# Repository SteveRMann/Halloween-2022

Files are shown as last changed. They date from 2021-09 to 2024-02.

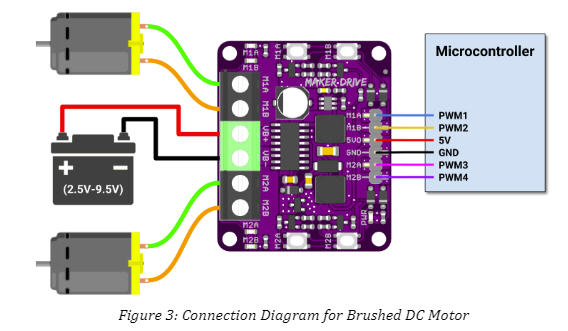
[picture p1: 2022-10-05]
tail-tentacle hardware/Maker Drive- H-Bridge Connections.jpg

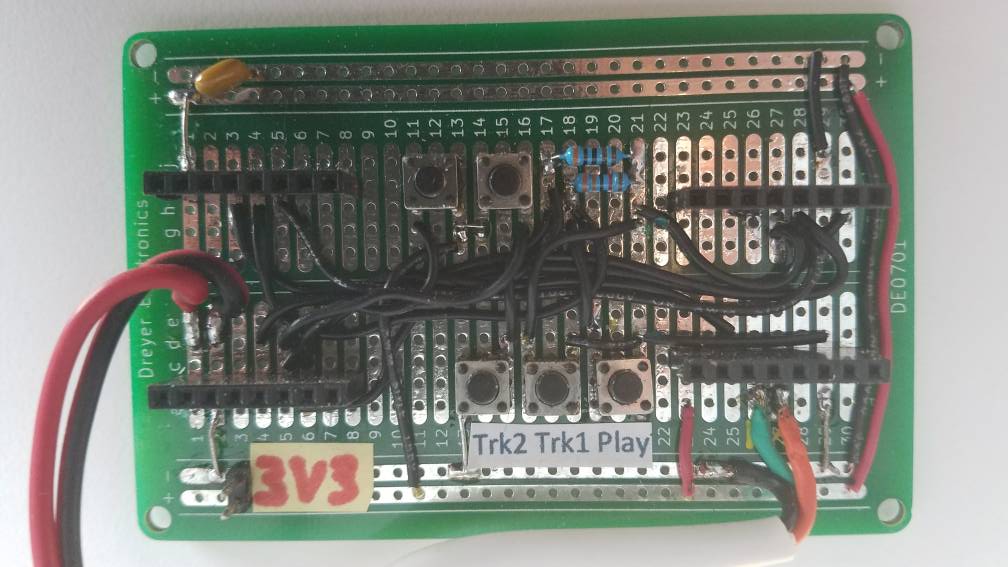
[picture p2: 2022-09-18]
Sounds/DFPlayer/Schematic/20220916_123933.jpg

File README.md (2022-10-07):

# MonsterBox
This project is further development of the 2021 monster in a box for Halloween.
The biggest change is the addition of a bubble generator.

## Crate Ideas
Contains images and ideas for the crate construction

## Fan
Contains the schematic files for the fan and LED MOSFET controller.

## Notes
Just contains random notes used while making the box

## Sounds
Contains the sound files and editing information. It also contains the DFPlayer notes.

## src
### dfPlayer
This is the code that controls the sounds from the box

### HBridgeTest
Code to test the H-Bridge. This year we changed to a library to control the tail H-bridge

### Lid
Contains the Arduino source code for the lid mechanism.

### servoSweep
Code to sweep the servo 0-180 degrees.

### servoManualSweep
Code used to calibrate the PWM endpoints for servo.h

### tail
Code to make the sea monster's tail sweep back and forth.

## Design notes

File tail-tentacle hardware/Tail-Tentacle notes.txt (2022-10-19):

The original breadboard had a PINHD-1X8 for the input side, but the production version uses six pins.

Prototype pinout:
1 - Ground
2 - +5V
3 - Ground
4 - +5V
5 - 5V isolation if the ESP is to be powered from the USB
6 - +5V to the ESP
7 - External trigger button
8 - Ground

The production version:
2 - Connects to the limit switch on D5

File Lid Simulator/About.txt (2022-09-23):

This is a motor controller for the lid simulator

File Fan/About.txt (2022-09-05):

The fan in the crate blows the fog out of the lid.

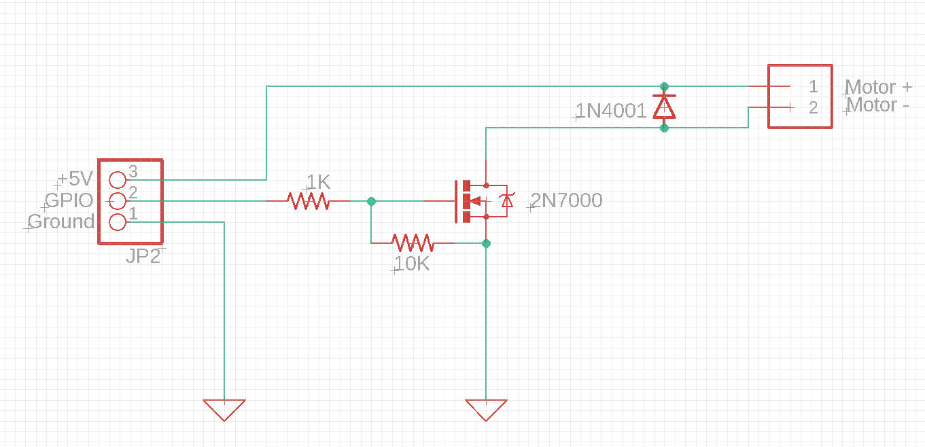
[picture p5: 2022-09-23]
Lid Simulator/Lid Simulator Schematic.jpg

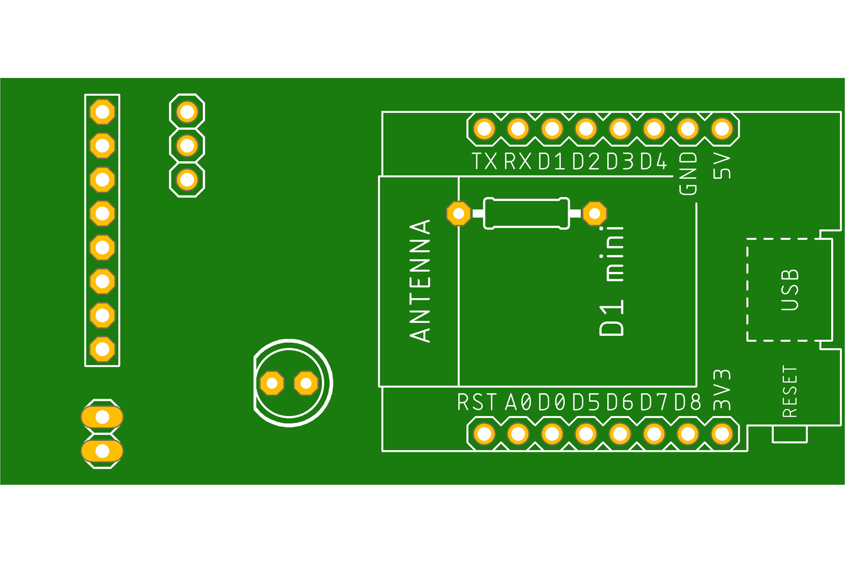
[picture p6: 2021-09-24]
tail-tentacle hardware/tail.png

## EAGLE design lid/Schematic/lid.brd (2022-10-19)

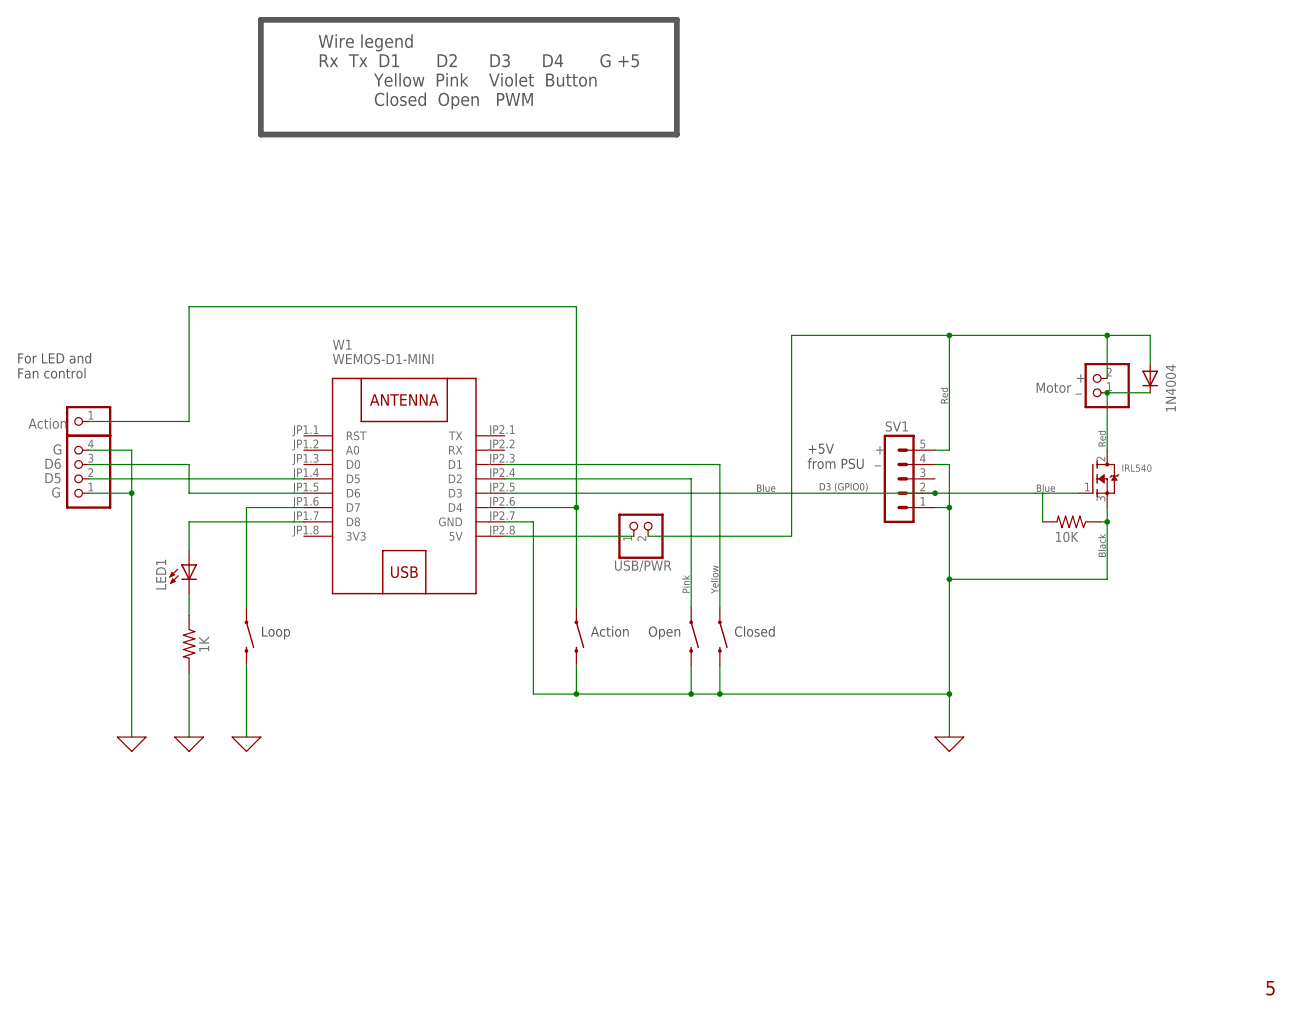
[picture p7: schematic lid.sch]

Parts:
ACTION, ACTION1: MOMENTARY-SWITCH-SPST-PTH-6.0MM; TACTILE_SWITCH_PTH_6.0MM
D1: 1N4004; DO41-10
JP1: PINHD-1X1; 1X01
JP3: PINHD-1X2; 1X02
JP4: PINHD-1X4; 1X04
LED1: LED5MM
Q1: IRL540; TO220V
R1: 1K; 0207/10
R4: 10K; 0207/10
S1, S2: MOMENTARY-SWITCH-SPST-PTH-6.0MM; TACTILE_SWITCH_PTH_6.0MM
SV1: MA05-1
USB/PWR: PINHD-1X2; 1X02
W1: WEMOS-D1-MINI

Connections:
0: ACTION.3 (2), ACTION1.3 (2), JP4.1, JP4.4, Q1.3 (S), R1.2, R4.1, S1.3 (2), S2.3 (2), SV1.1, SV1.4, W1.JP2.7 (GND)
3V3: W1.JP1.8 (3V3)
unnamed: Q1.1 (G), R4.2, SV1.2, W1.JP2.5 (D3)
unnamed: D1.C, JP3.1, Q1.2 (D)
unnamed: D1.A, JP3.2, SV1.5, USB/PWR.2
unnamed: S1.1, W1.JP2.4 (D2)
unnamed: S2.1, W1.JP2.3 (D1)
unnamed: LED1.A, W1.JP1.7 (D8)
unnamed: LED1.K (C), R1.1
unnamed: USB/PWR.1, W1.JP2.8 (5V)
unnamed: ACTION.1, JP1.1, W1.JP2.6 (D4)
unnamed: JP4.2, W1.JP1.4 (D5)
unnamed: JP4.3, W1.JP1.5 (D6)
unnamed: ACTION1.1, W1.JP1.6 (D7)

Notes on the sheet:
Motor
+5V from PSU
D3 (GPIO0)
Open
Closed
Yellow
Pink
Blue
Black
Red
Action
Wire legend Rx Tx D1 D2 D3 D4 G +5 Yellow Pink Violet Button Closed Open PWM
For LED and Fan control
Loop

Board: 2 copper layers, 15 parts (0 on the bottom side), 13 nets, no tracks yet.

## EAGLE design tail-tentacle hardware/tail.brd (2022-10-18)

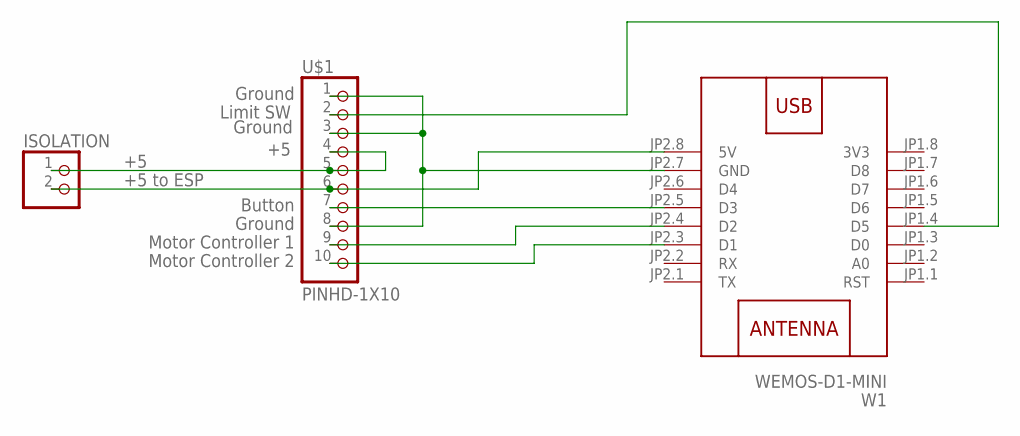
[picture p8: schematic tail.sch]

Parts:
ISOLATION: PINHD-1X2; 1X02
U$1: PINHD-1X10; 1X10-BIG
W1: WEMOS-D1-MINI

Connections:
3V3: W1.JP1.8 (3V3)
unnamed: U$1.7, W1.JP2.5 (D3)
unnamed: U$1.9, W1.JP2.4 (D2)
unnamed: U$1.10, W1.JP2.3 (D1)
unnamed: ISOLATION.1, U$1.4, U$1.5
unnamed: ISOLATION.2, U$1.6, W1.JP2.8 (5V)
unnamed: U$1.2, W1.JP1.4 (D5)
unnamed: U$1.1, U$1.3, U$1.8, W1.JP2.7 (GND)

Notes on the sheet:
Limit SW
Ground
Button
Motor Controller 1
Motor Controller 2
+5 to ESP

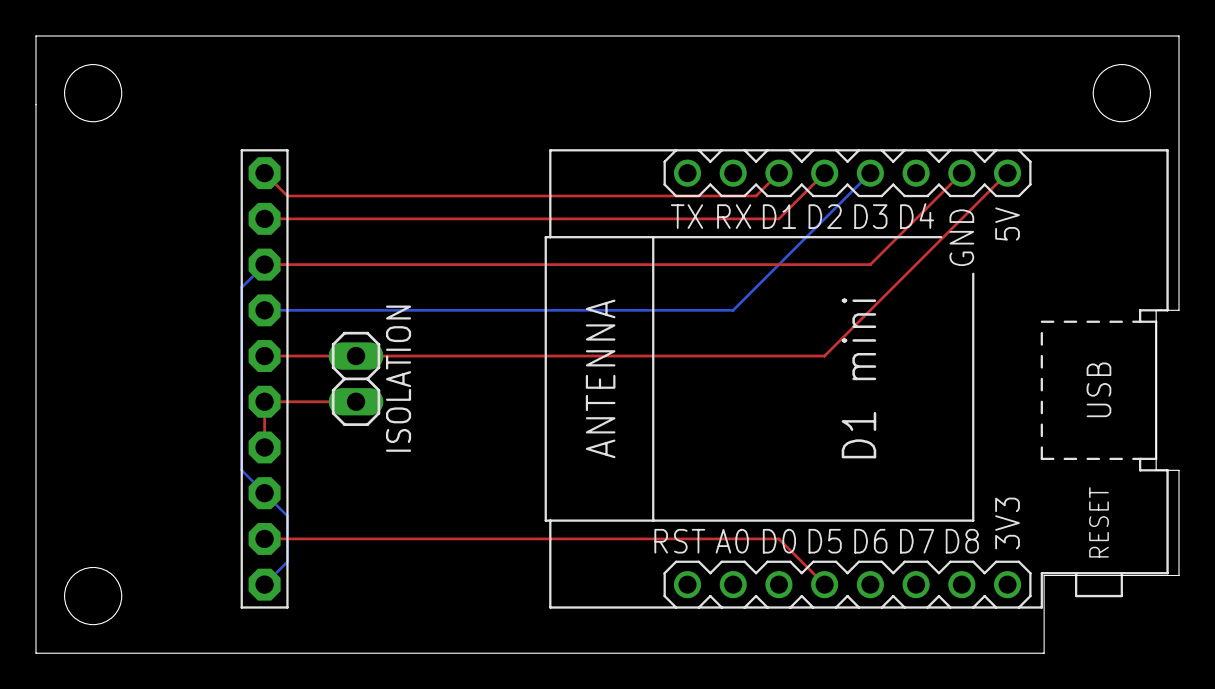
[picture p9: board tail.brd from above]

Board: 2 copper layers, 63.5 x 34.3 mm, 3 parts (0 on the bottom side), 7 nets.

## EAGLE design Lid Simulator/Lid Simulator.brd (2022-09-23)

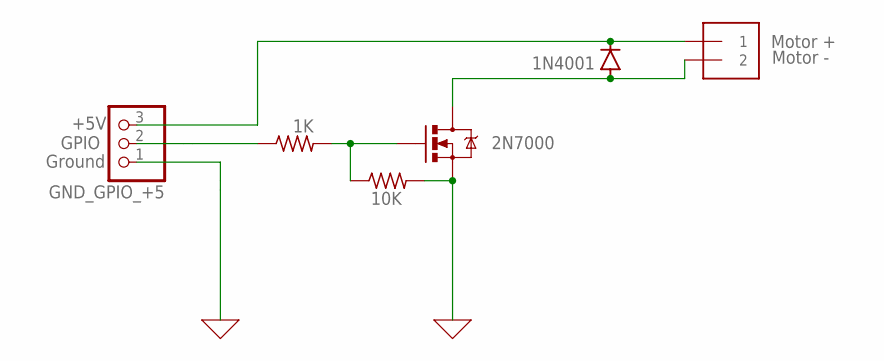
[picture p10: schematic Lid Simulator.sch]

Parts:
D1: 1N4001; DO-41
GND_GPIO_+5: PINHD-1X3CB; 1X03-CLEANBIG
MOTOR_-__+: 1X2-3.5MM
Q1: MOSFET-NCHANNEL2N7000; TO-92
R1: 1K; 0207/10
R2: 10K; 0207/10

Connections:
0: GND_GPIO_+5.1, Q1.1 (S), R2.2
unnamed: D1.A, MOTOR_-__+.2, Q1.3 (D)
unnamed: Q1.2 (G), R1.2, R2.1
unnamed: GND_GPIO_+5.2, R1.1
unnamed: D1.C, GND_GPIO_+5.3, MOTOR_-__+.1

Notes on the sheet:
Motor +
Motor -
+5V
GPIO
Ground
2N7000

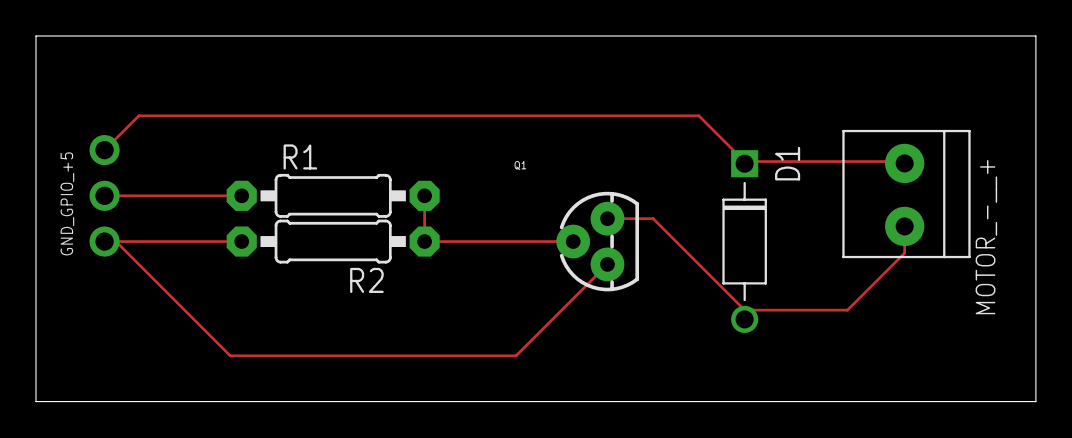
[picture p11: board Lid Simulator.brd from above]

Board: 2 copper layers, 55.5 x 20.3 mm, 6 parts (0 on the bottom side), 5 nets.

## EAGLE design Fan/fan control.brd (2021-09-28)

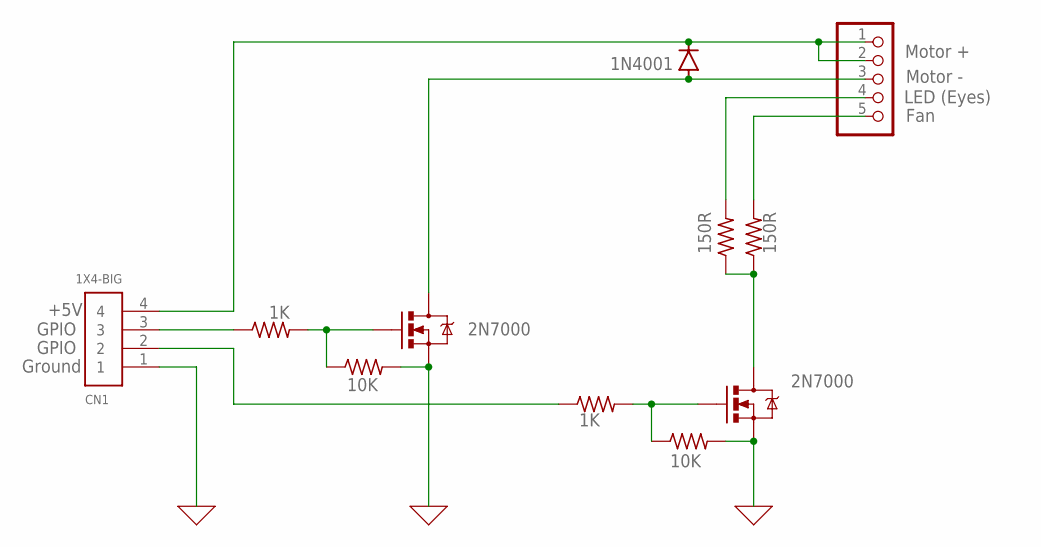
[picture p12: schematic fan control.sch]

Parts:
CN1: 1X4-BIG; 1X04-BIG
D1: 1N4001; DO-41
JP1: PINHD-1X5; 1X05
Q1, Q2: MOSFET-NCHANNEL2N7000; TO-92
R1, R3: 1K; 0207/10
R2, R4: 10K; 0207/10
R5, R6: 150R; 0207/10

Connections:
0: CN1.1, Q1.1 (S), Q2.1 (S), R2.2, R4.2
unnamed: CN1.4, D1.C, JP1.1, JP1.2
unnamed: Q1.2 (G), R1.2, R2.1
unnamed: CN1.3, R1.1
unnamed: D1.A, JP1.3, Q1.3 (D)
unnamed: Q2.2 (G), R3.2, R4.1
unnamed: Q2.3 (D), R5.1, R6.1
unnamed: CN1.2, R3.1
unnamed: JP1.5, R6.2
unnamed: JP1.4, R5.2

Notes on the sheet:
Motor +
Motor -
+5V
GPIO
Ground
2N7000
LED (Eyes)
Fan

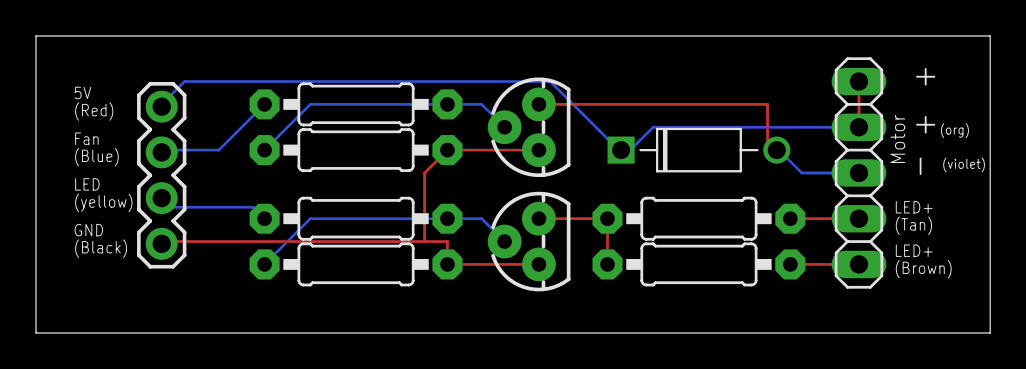
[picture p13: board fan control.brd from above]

Board: 2 copper layers, 53.0 x 16.5 mm, 11 parts (0 on the bottom side), 10 nets.

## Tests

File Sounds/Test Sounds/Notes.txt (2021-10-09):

These are simply a voice saying: "Track One", "Track two", etc.

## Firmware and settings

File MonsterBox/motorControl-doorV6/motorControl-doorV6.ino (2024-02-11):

#define SKETCH_NAME "monsterBox"
#define SKETCH_VERSION "6.0"

/*
   Brushed Motor Speed Control
   Using Wemos D1 Mini

   Project is a monster box. The motor slightly opens the box periodically
   and randomly. Inside the box will be a second motor that spins a chain
   to make noise.
*/

#define TENSEC 10000
#define FIVESEC 5000

const int motorPin = D1;
const int startSwitch = D2;               //Starts the motor
const int closedSwitch = D3;              //Limit pin, stops the motor
const int openSwitch = D4;                //Limit pin, stops the motor
const long int Minutes = 60000;           //ms per minute
const long int Seconds = 1000;            //ms per second
bool flagMotorOn = false;
const int MIN_PWM = 200;                   //Anything lower and the motor won't start
int motorPwm = MIN_PWM;                   //PWM value for motor on.
int lidState;
int bounceCount = 0;
int motorState = 0;



//--------------- WiFi declarations ---------------
// WiFi declarations
#include <ESP8266WiFi.h>        // Not needed if also using the Arduino OTA Library...
#include <Kaywinnet.h>          // WiFi credentials
char macBuffer[24];             // Holds the last three digits of the MAC, in hex.
char hostName[24];              // Holds nodeName + the last three bytes of the MAC address.
char nodeName[] = SKETCH_NAME;  // Give this node a name



//--------------- OTA declarations ---------------
#include <ArduinoOTA.h>



//--------------- MQTT declarations ---------------
#include <ESP8266WiFi.h>        // Connect (and reconnect) an ESP8266 to the a WiFi network.
#include <PubSubClient.h>       // connect to a MQTT broker and publish/subscribe messages in topics.
// Declare an object of class WiFiClient
// Declare an object of class PubSubClient, which receives as input of the constructor the previously defined WiFiClient.
// The constructor MUST be unique on the network. (Does it?)
WiFiClient monsterBox;
PubSubClient client(monsterBox);

// Declare strings for the topics. Topics will be created in setup_mqtt().
char statusTopic[20];
char cmndTopic[20];
char rssiTopic[20];
const char *mqttServer = MQTT_SERVER;         // Local broker defined in Kaywinnet.h
const int mqttPort = 1883;



//--------------- ticker ---------------
//Function prototype must precede the ticker init
//void motorStart();

//#include <Ticker.h>
//Ticker motorTimer;



//=============== setup ===============
void setup() {
  beginSerial();
  setup_wifi();
  start_OTA();
  setup_mqtt();                         //Generate the topics
  client.setServer(mqttServer, mqttPort);
  mqttConnect();


  Serial.println(F("Starting"));

  pinMode(closedSwitch, INPUT_PULLUP);
  pinMode(openSwitch, INPUT_PULLUP);
  pinMode(startSwitch, INPUT_PULLUP);

  // Start the motor periodically
  //  motorTimer.attach(8.0, motorOn);

  lidState = 0;     //Open
}


//=============== loop ===============
void loop() {
  ArduinoOTA.handle();
  mqttReconnect();         //Make sure we stay connected to the mqtt broker

  closeTheLid();
  delay(FIVESEC);
  openTheLid();
  delay(FIVESEC);

  /*
  closeTheLid();
  delay(6000);

  //Thrash the lid
  motorPwm = 200;                   //Fast
  for (int i = 0; i < 5; i++) {
    openTheLid();
    closeTheLid();
  }
  motorPwm = MIN_PWM;               //Default speed
  delay(15000);
  */
}


// ========= Start the motor =========
void startTheMotor() {
  //Serial.print(F("motor "));
  analogWrite(motorPin, motorPwm);            //Turn on the motor to motorPwm
  motorState = 1;                             //Just used to print debug statements only once.
  delay(100);                                 //Give the motor time to move past the stop switch.
  //Serial.println(F("ON"));
}

// ---------- Open the lid ----------
void openTheLid() {
  startTheMotor();
  while (digitalRead(openSwitch)) yield();    //Wait for the limit switch
  analogWrite(motorPin, 0);                   //Stop the motor
  if (motorState == 1) {                      //Just print once
    Serial.println(F("OPEN"));
    motorState = 0;
  }
}

// ---------- Close the lid ----------
void closeTheLid() {
  startTheMotor();
  while (digitalRead(closedSwitch)) yield();  //Wait for the limit switch
  analogWrite(motorPin, 0);                   //Stop the motor
  if (motorState == 1) {                      //Just print once
    Serial.println(F("CLOSED"));
    motorState = 0;
  }
}



//=============== motorOn ===============
//Function called by the ticker.
void motorOn() {
  //Serial.println(F("Tick"));
  flagMotorOn = true;
  lidState += 1;
  if (lidState > 2) lidState = 0;
}

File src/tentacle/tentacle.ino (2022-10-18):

#define SKETCH "tentacle"
#define VERSION "1.0"

#define LEDOFF LOW
#define LEDON HIGH
//#define LEDPIN D4               //LED_BUILTIN on most boards
#define LEDPIN D6
#define LIMITPIN D5

int motorState = 0;
bool motorDirection = false;

const int SPEED = 48;
int motorSpeed = SPEED;

// Configure the motor driver.
#include "CytronMotorDriver.h"
CytronMD motor1(PWM_PWM, D1, D2);   // PWM 1A = Pin D1, PWM 1B = Pin D2.



// --------------- ticker declarations ---------------
#include <Ticker.h>
Ticker wagTicker;
int tickerInterval = 1000;      //Time between wags?
bool wagFlag = false;


// --------------- Limit Switch Interrupt Handler ---------------
IRAM_ATTR void limitSwitchHandler() {
  static unsigned long last_interrupt_time = 0;
  unsigned long interrupt_time = millis();
  // If interrupts come faster than 20ms, assume it's a bounce and ignore
  if (interrupt_time - last_interrupt_time > 20) {
    //Not a bounce, do your thing
    motorState = 2;
  }
  last_interrupt_time = interrupt_time;
}


// ----- Function to randomize wags -----
void periodicWag() {
  wagFlag = true;                                   //We can't put wag() here in a callback because it uses delay()
  tickerInterval = random(1000, 6000);
  Serial.print(F("tickerInterval= "));
  Serial.println(tickerInterval);
  wagTicker.detach();
  wagTicker.attach_ms(tickerInterval, periodicWag); //Start the timer to the next wag.
}



void setup() {
  // -------------- beginSerial() --------------
  while (!Serial);
  Serial.begin( 115200 );
  Serial.println();
  Serial.println();
  Serial.print(SKETCH);
  Serial.print(".ino, Version ");
  Serial.println(VERSION);
  Serial.println(F("++++++++++++++++++ +"));

  //Setup the GPIO pins
  pinMode(LEDPIN, OUTPUT);
  digitalWrite(LEDPIN, LEDOFF);
  pinMode(LIMITPIN, INPUT_PULLUP);
  attachInterrupt(digitalPinToInterrupt(LIMITPIN), limitSwitchHandler, FALLING);

  motorState = 0;
}



void motorStart(int speed) {
  //Start the motor long enough to get past the limit switch
  motor1.setSpeed(speed);         //Turn on the motor
  delay(100);                      //Let the motor turn past the limit switch
  motor1.setSpeed(speed / 2);     //Slow the motor down
}


void loop() {
  switch (motorState) {
    case (0):
      //Motor is stopped, start it and move to case 1
      motorStart(motorSpeed);
      motorState = 1;
      break;
    case (1):
      //Start the motor running, waiting for interrupt to set state to 2
      digitalWrite(LEDPIN, LEDON);
      break;
    case (2):
      //Interrupt happened. Stop the motor and move to state 3
      motor1.setSpeed(0);         //Stop motor
      delay(500);
      motorState = 3;
      break;
    case (3):
      //Delay ended, toggle direction and move to state 3
      motorSpeed = motorSpeed * -1;
      motorState = 4;             //Start over in the opposite direction
      break;
    case (4):
      //Delay between wags then go back to state 0 to start over.
      delay(1000);
      motorState = 0;
      break;
  }
}

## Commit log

2021-09-21 Add files via upload
    eggDropTest is the terminal version of the program. Used for testing servo operation and timing.
2021-09-25 Added OneButton.h library for single, double and long button presses
2021-09-27 Added lid schematic
    [lid.sch]
2021-09-28 Changed GPIO pin numbers.
2021-09-28 Added LED/FAN GPIO ports
    [lid.sch]
2021-09-28 Added LED and FAN GPIO ports
    [lid.sch]
2021-09-28 Changed schematic filename
2021-10-06 Added button multifunction to eggDrop
2021-10-09 Refresh the git
    [lid.sch, timing.xlsx]
2021-10-10 Added Pumpkin Videos directory to gitignore.
2021-10-11 timings for the sync feature
    [timing.xlsx]
2021-10-11 Changed the exit servo zero position.
2021-10-12 Update functions.ino
    Reduce the delay for letting the motor move past the limit switches. This, of course, assumes that the motor actually stoppen ON a liit switch.
2021-10-12 Update setup.ino
    Temp- commented out the timers starts.
2021-10-13 Update functions.ino
    startTheMotor(), changed the delay after startup to just testing the switches. Also slowed the run speed.
2021-10-14 Update functions.ino
    Removed some superfluous print statements
2022-09-05 Update notes and lid schematic
    Update notes and lid schematic
2022-09-19 Moved video folders to videos folder
    [eggDrop.brd, eggDrop.sch]
2022-09-23 Added simulator
    [Lid Simulator.brd, Lid Simulator.sch]
2022-09-25 Added motortest
2022-10-05 Many changes
    Added HBridgeTest.ino, cleaned up functions.ino, added namespaces, removed mqtt.ino; added myMqtt.h, added myFunctions.h, myMqtt.h,, WifiMulti.h, removed ota.ino; added myOTA.h, cleaned up setup.ino 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
    [tail.brd, tail.sch]
2022-10-12 Mostly changing the motor timers to a state machine.
2022-10-15 Corrected spelling
    On the PC, #include is not case sensitive. It is on Linux.
    [tail.brd, tail.sch]
2022-10-18 Changed tail to tentacle
    [tail.brd, tail.sch]
2022-10-19 Made dfplayer2 from dfplayer, without mqtt or console menu.
    [lid.brd, lid.sch]
2022-10-27 Added code for rats and testing servo

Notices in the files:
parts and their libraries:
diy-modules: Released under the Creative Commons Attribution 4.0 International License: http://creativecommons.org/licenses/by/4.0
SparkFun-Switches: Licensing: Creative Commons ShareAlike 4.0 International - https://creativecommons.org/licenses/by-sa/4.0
